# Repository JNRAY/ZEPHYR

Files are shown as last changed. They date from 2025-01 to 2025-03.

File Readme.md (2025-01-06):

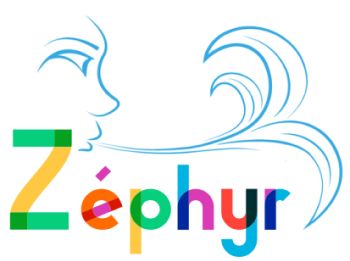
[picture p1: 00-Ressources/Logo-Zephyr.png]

## Network of sensors monitoring air quality parameters.  
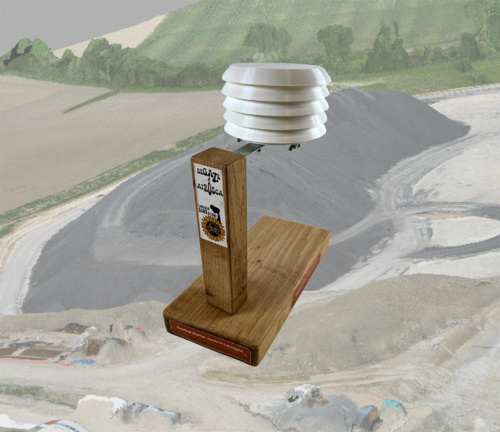
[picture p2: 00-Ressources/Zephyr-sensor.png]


*The Zéphyr sensor on its demonstration support and in the background of the image the pile of gravel from the Puylaurens power plant.*

The Zéphyr sensor is an instrument that measures up to 9 physical air quality parameters:

* Particles from 1 to 10µm: PM1, PM2.5, PM4 and PM10 
* Volatile Organic Compounds VOCs
* Nitrogen Oxides Nox
* Air humidity
* Ambient temperature
* CO2 content (optional)  

It was developed during the fight against the A69 motorway project (Tarn/Haute-Garonne, Occitanie region in France) to oppose the establishment of two bitumen asphalt mixing plants whose authorities government authorities did not fully appreciate public health and environmental issue**s.

The operation was carried out at the initiative of the Lauragais Sans Bitume [LSB](https://www.lauragais-sansbitume.fr/) collective, supported by 11 other local bitumen-free collectives.

The sensors and the computer architecture to manage the data were designed by a group of enlightened amateurs from the territory impacted by the power plants, supported by the Granas de Carderas association which distributes the sensors from its [HelloAsso](https://www.helloasso.com/associations/granas-de-carderas) sales website.

The sensors deployed (more than 60 to date) send their data every 5 minutes to a server which allows the owners of the sensors to access a dashboard and everyone to view the mapping of the quality of air in real time.

[For more information see our GitBook site:](https://rhizobiome.gitbook.io/atrosca-degaze)

## *Credits*

We would like to thank the people who participated, on a voluntary basis, in this initiative.
The people involved were able to provide their skills in various areas to make this project a reality:

* Design & technical design of circuits to operate sensors
* 3D printing and assembly of the boxes in which the sensors are embedded
* Provision of a server and hosting
* Integration of applications (open source) used to collect data
* Development of the dasboards presented here
* Coordination of the project and all the skills necessary to achieve this result

All this without forgetting the contributors who took the step of acquiring a Zéphyr sensor and making the measurements taken by them available.
THANKS !!

[Zéphyr](https://rhizobiome.gitbook.io/atrosca-degaze) © 2024 [LSB](https://www.lauragais-sansbitume.fr/) under the [CC BY-NC-SA 4.0](https://creativecommons.org/licenses/by-nc-sa/4.0/?ref=chooser-v1) Licence

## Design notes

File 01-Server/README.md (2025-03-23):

# LSB Server

_Page describing integration of so-called "LSB server", a solution designed to collect data from air quality sensors based on Sensirion SEN55 and SCD30 sensors driven by an ESP32 SOC_

# Foreword

## Open-source Software

In order to properly collect and expose data in the contxt for which this project has been set up, we intend to use only open-source and free-to-use software in order to keep costs low and show transparency to those that will provide and use the data we'll be providing.

Additionally, we don't intend to infringe any copyright or proprietary usage limitation by editors of software we choosed to rely on. We think that we're respecting this moto, but as there are many software and licenses involved here: this a complex situation. If you notice any chance that we're not respecting any of those: please notify us so can investigate and remediate...

## Prerequisites

Below are the assumptions that are made in order to properly host the software that are used in this context.

- You dispose of a server with **docker** and **docker compose** plugin installed.
- You dispose of a way to expose the server on the internet: either a hosted service or a broadband.
- You have a domain, prerefarably with a wildcard DNS resolution for any subdomains, to properly host web interfaces that will be built & used.
- You have a letsencrypt account in order to create SSL/TLS certificates used by those interfaces

# Technical documentation

We tried to stay as "standard" as possible, using official releases/images whenever possible and avoided customizing too much the software we integrated so this can be repeated and adapted by other willing to build analog solutions. Don't hesitate to refer to each used software documentation to understand and/or customize configuration to fit your needs and situation.

In the files provided in this repository, mostly docker-compose.yml file, one should consider replacing keywords between `<` and `>` by assets suited to its specific situation or configuration: those can be domain names, IPs, passwords, ...  
=> As a consequence, you'll have to edit/review all files when cloning this repository: comments embedded in files will help filling those values and provide guidance.

We prefered usage of publicly available **docker** images in order to allow better reproductibility of what we've done, so anyone can benefit from the work and design proposed here.  
**Docker** usage also allow for ease of use, configuration and backup of the solution.

## Installation

Please read through the whole **installation** chapter before jumping to **usage** and/or ask questions: many integration details are documented here.

### Clone git repo

As **root** user, if not already done, create a **docker** user, preferably with gid/uid = 1000 and clone this repo as this user's home folder:
```
useradd -u 1000 -g 1000 -b /home/docker -M docker
cd /home
git clone <REPO_URL>
mv REPO_NAME/docker ./
chown -R 1000:1000 ./docker
chown -R 472 ./docker/grafana

```
Now, just go trough all files, looking for keywords as mentioned earlier in order to put your values in place of those so you'll have usable configurations.

=> Below, you'll find a list of all keywords that would need to be replaced once repo is cloned:

| Keyword | File | Usage |  
|---|---|---|
| YOUR_DOMAIN | docker/traefik/docker-compose.yml | The domain name that will be used to host solution |
| YOUR_LETSENCRYPT_USER_EMAIL | docker/traefik/config/traefik.yml | Email of owner that is used for Letsencrypt SSL certificate |
| TRAEFIK_USER | docker/traefik/config/dynamic/middlewares.yaml | User to connect to Traefik web ui |
| TRAEFIK_PASSWORD | docker/traefik/config/dynamic/middlewares.yaml | Password for above user |
| TRAEFIK_PASSWORD | docker/traefik/config/dynamic/middlewares.yaml | Password hash of above password |
| YOUR_TRUSTED_IP | docker/traefik/config/dynamic/middlewares.yaml | Public IP that you trust (ex: admins of the solution, so they can connect though Traefik filtering |
| YOUR_DOMAIN | docker/wireguard/docker-compose.yml | The domain name that will be used to host solution |
| YOUR_PUBLIC_FQDN | docker/wireguard/docker-compose.yml | FQDN that will be used for VPN clients, likely `vpn.<YOUR_DOMAIN>` |
| WIREGUARD_BCRYPT_PASSWORD_HASH | docker/wireguard/docker-compose.yml | Hash of the password used to acces Wireguard admin web UI. Beware of carefully reading editor documentation that comment in the file points you to for hash generation...|
| PRIVATE_IP_OF_SERVER | docker/wireguard/docker-compose.yml | Private IP of system that will be used to host solution |
| MQTT_USER | docker/mqtt/mosquitto/config/mosquitto.conf | Connection user for MQTT clients |
| YOUR_DOMAIN | docker/mqtt/telegraf-sensor/conf/telegraf.conf | The domain name that will be used to host solution |
| INFLUXDB_ORGANIZATION_NAME | docker/mqtt/telegraf-sensor/conf/telegraf.conf | Organization that you created on InfluxDB admin web UI |
| INFLUXDB_BUCKET_NAME | docker/mqtt/telegraf-sensor/conf/telegraf.conf | Name of bucket that you created on InfluxDB admin web UI |
| INFLUXDB_TOKEN_VALUE | docker/mqtt/telegraf-sensor/conf/telegraf.conf | Value of token for above bucket that you created on InfluxDB admin web UI |
| SENSORS_MQTT_TOPIC | docker/mqtt/telegraf-sensor/conf/telegraf.conf | Value of topic you choosed for sensors to send their metrics |
| MQTT_USER | docker/mqtt/telegraf-sensor/conf/telegraf.conf | User that Telegraf will use to get values from MQTT, that you created earlier in the installation process |
| MQTT_PASSWORD | docker/mqtt/telegraf-sensor/conf/telegraf.conf | Password corresponding to aboce user |
| YOUR_DOMAIN | docker/influxdb/docker-compose.yml | The domain name that will be used to host solution |
| YOUR_DOMAIN | docker/grafana/docker-compose.yml | The domain name that will be used to host solution |
| SMTP_SERVER_IP | docker/grafana/docker-compose.yml | IP of SMTP server to allow Grafana to send emails (optional) |
| SMTP_SERVER_PORT | docker/grafana/docker-compose.yml | Port of SMTP server to allow Grafana to send emails (optional) |
| SMTP_SENDER_EMAIL | docker/grafana/docker-compose.yml | Sender adress used by Grafana to send emails (optional) |
| GRAFANA_ORGANIZATION_NAME | docker/grafana/docker-compose.yml | Organization (you created in Grafana web UI) to allow to publicly expose dashboards without users authentication (optional) |
| PUT_DASHBOARD_DESCRIPTION_HERE | docker/grafana/sen55-graphs.json | Description of the dashboard for users to understand what's in the dashboard |
| SENSOR_DATASOURCE_ID | docker/grafana/sen55-graphs.json | ID of datasource you creaated in Grafana web UI, pointing to InfluxDB bucket for sensors collected data |
| SENSOR_MQTT_TOPIC | docker/grafana/sen55-graphs.json | MQTT topic used by sensors to send data to MQTT |
| PUT_DASHBOARD_DESCRIPTION_HERE | docker/grafana/scd30-graphs.json | Description of the dashboard for users to understand what's in the dashboard |
| SENSOR_DATASOURCE_ID | docker/grafana/scd30-graphs.json | ID of datasource you creaated in Grafana web UI, pointing to InfluxDB bucket for sensors collected data |
| SENSOR_MQTT_TOPIC | docker/grafana/scd30-graphs.json | MQTT topic used by sensors to send data to MQTT |

### Docker configuration

To avoid IP conflict with local network and fix some enrtypoints, we fixed the IP used bu docker, especially the **docker0** bridge interface.  
=> This is done by configuring it in `/etc/docker/daemon.json` fille: refer to the `daemon.json` file in the root of this repository.

### Folder structure

For hosting containers, we choosed to add a **docker** user to the system (user without any admin privileges with uid/gid=1000), but any user will do.  
=> As a consequence, the `docker` folder in this repo is actually the `/home/docker` folder on the server: you may need to adapt volumes path in the compose files to your situation. But, the easier would be to stick to this structure, so you'll have minimal changes to carry out in compose files.

### Traefik

To allow quick and easy configuration and hosting of web interfaces, we rely on the **traefik** container which is a reverse proxy able to generate SSL certificates from **Letencrypt** for each subdomain that will be used in other containers.  

Port 80, should be exposed to the internet so **traefik** can automatically generate SSL certificates through **Letencrypt** certificate athority.  
Port 443 is only needed if you're willing to expose the WebUIs to the internet: but beware of using proper filtering and secure passwords on your interfaces if you're hoing that way !

### Wireguard

A Wireguard VPN will be used so sensors can connect to server to push air-quality measures to server: we choose to use the **wgeasy** container to allow easy wireguard integration/configuration.  

Although it is a docker container, and on CentOS at least, this needs a bit of system tuning on server by adding the `ip_tables` module to kernel at boot time: you should add commands to your `/etc/rc.local` file: see the `rc.local` file in the `docker/wireguard` folder of this repo (or possibly create a file in the `/etc/modprobe.d/` to have this module probed at start-up).  
We prefered the `rc.local` solution as we've added a restart for **mosquitto** container as it does not properly starts on every reboot the server may experience.

### InfluxDB

In order to store measures sent by sensors, we need a DB able to handle so called "time-series": we choosed **InfluxDB**.  
When running container for first time, you'll have to create via web UI:

* an organization
* a bucket (= a DB) for sensor data
* optional: a bucket for weather data, if you choose to collect weather from external sources
* a token with write permission to each bucket for Telegraf (to be used in **mqtt** docker stack)
* a token with read permission to each bucket for Grafana (to be used in **grafana** docker stack)

### MQTT

Sensors send data using MQTT protocol to the server. For the MQTT stack, we choose to use **mosquitto** container as a MQTT broker and **telegraf** as client to get MQTT messages.

A single docker compose file for both container is in the `docker/mqtt` folder of this repo.  
It also contains additional telegraf container for collecting weather data from a public station so we can display wind direction and speed on a map with sensors (see the **grafana** stack).

### Grafana

To display sensors data in bashboards, **Grafana** is a perfect tool.  
Container use a specific uid (472) when running, so don't omit to `chown -R 472 /home/docker/grafana` after cloning this repo.

We have set up dashboards showing graphs and maps with sensors:

* create datasources in Grafana web UI corresponding to each InfluxDB bucket and note their ID aside. When adding datasources, you'll need to use bucket tokens created earlier and user HTTP header authentication. Refer to [Grafana documentation about InfluxDB datasource](https://grafana.com/docs/grafana/latest/datasources/influxdb/configure-influxdb-data-source/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)
* refer to JSON files in `docker/rafana` folder of this repo: those have to be imported in the web UI, then adapted to you situation (datasource ID, locations, sensor names, ...).

## Usage

### Accesses
Once installation is properly done, you should consider below recapitulative information to properly  use the solution:

<u>Ports to be publicly exposed:</u>

| Port | Protocol | Usage |
|---|---|---|
| 80 | TCP | For Traefik to be able to generate SSL certificates |
| 443 | TCP | Optional: to publicly expose web UI, if needed |
| 51820 | UDP | For sensors to extablish Wireguard VPN connection |

<u>Available web UI URLs:</u>

| URL | Usage |
|-----|---|
| `https://air-quality.<YOUR_DOMAIN>` | Grafana web UI, used for administration and exposing dashboards |
| `https://influxdb.<YOUR_DOMAIN>` | InfluxDB admin web UI and API used as Grafana datasource |
| `https://traefik.<YOUR_DOMAIN>` | Traefik dashboard, to view & check reverse proxy configuration |
| `https://vpn.<YOUR_DOMAIN>` | Wireguard admin web UI used to create & view VPN accounts for sensors. It is also the VPN server address to be used in the ESP32 code |

### VPN keys

First thing is to create a VPN account for a sensor (one account for each sensor) on the Wireguard web UI.  
As ESP32 library in the code from [ESP32 code repo](https://repo.url) does not take into account pre-shared key, they'll have to be removed from configuration that the webmin created.
To achieve this, stop the wireguard container and edit the `docker/wireguard/data/wg0.json` file and remove the value for `preSharedKey` for each account you created but keep the key in the file or another one will be created, as shown in below snippet example:

```json
(...)
"preSharedKey": "",
(...)
```

### Configure sensor

Refer to [ESP32 code repo](https://github.com/JNRAY/ZEPHYR/tree/main/02-Sensor/03-XIAO-C3-code#:~:text=03%2DXIAO%2DC3%2D-,code) and include VPN keys in header file before compilation and upload firware to ESP32.  
When sensor is restarted and configured to connect to a Wifi network, you should be able to see it connecting at MQTT level by looking to **mosquitto** container logs.

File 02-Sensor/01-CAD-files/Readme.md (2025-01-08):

### Cad Files

Cad files in Fusion 360 and STEP format

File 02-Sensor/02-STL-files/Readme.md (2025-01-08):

### Print settings
Filament material: PLA

* Color: white.
* Infill: 20%.
* Resolution: 0.2.
* For intermediate level, Top cover  and Sensor support, Supports: Yes.
* For Bottom, Support: No.

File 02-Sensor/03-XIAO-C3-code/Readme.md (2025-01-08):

# Zéphyr XIAO-C3 code installation and Download

## Basic software installation

### Install Vscode

Go to [https://code.visualstudio.com/]() and download the stable build for your operating system.

Launch Vscode.

### Instam PlatforIO extension on Vscode

In Vscode Extension seache and load PlartforIO IDE

Download XIAO-ESP32-C3 source code folder and copy in your conputer, open it from PIO Home/Open Project Quick Acess Menu.

## Zéphyr code configuration

You need to replace the values betxeen < > for:

### Server Configuration

From line 64 to 96 you need to update the folloving variables depending on your server configuration.

Name of the .h include file:

`<SEN55_SENSOR_ID>` (e.g. SEN55-001 or SCD30-001 if CO2 captor is installed)

Wireguard Configuration:

`public_key`&nbsp;&nbsp;&nbsp;&nbsp;&nbsp;&nbsp;&nbsp;&nbsp;&nbsp;&nbsp;&nbsp;&nbsp;&nbsp;&nbsp;`<WIREGUARD_PUBLIC_KEY>`  
`endpoint_address` `<YOUR_DOMAIN>`  
`endpoint_port` &nbsp;&nbsp;&nbsp;&nbsp;&nbsp;&nbsp;`<WIREGUARD_PORT>`

MQTT configuration:

`mqtt-Server` &nbsp;&nbsp;&nbsp;`<MQTT_SERVEUR_IP>`  
`mqttPort `&nbsp;&nbsp;&nbsp;&nbsp;&nbsp;&nbsp;&nbsp;&nbsp;&nbsp;&nbsp;`<MQTT_SERVEUR_PORT>`  
`mqttUser` &nbsp;&nbsp;&nbsp;&nbsp;&nbsp;&nbsp;&nbsp;&nbsp;&nbsp;`<MQTT_USER>`  
`mqttPassword` &nbsp;`<MQTT_PASSWORD>`

### Include .h file configuration for each captor

There is one .h include file for each sensor:

Sensor name and plant location:

`sensor` `SEN55-<SENSOR_ID>` (e.g. SEN55-001 or SCD30-001 if CO2 captor is installed)  
`zone` &nbsp;&nbsp;&nbsp;&nbsp;`<PLANT_LOCATION>` (Several plant location could be used if needed)

Sensor position (Used for the cartography in Grafana):

`longi` `<LONGITUDE>` of the Sensor  
`lat` &nbsp;&nbsp;&nbsp;&nbsp;`<LATITUDE>` of the Sensor

Mqtt Topic:

`topic` `<SENSOR_MQTT_TOPIC/SEN55-SENSOR_ID>`D (e.g. Environement/SEN55-001)

Wireguard configuration:

`privatr_key` `<WIREGUARD_PRIVATE_KEY>`  
`local_ip` &nbsp;&nbsp;&nbsp;&nbsp;&nbsp;&nbsp;`<WIREGUARD_SENSOR_IP>`

### Other configurations

From line 30 to 63 there is 4 viriables (See comment for definition):

`DEBUG`	&nbsp;&nbsp;&nbsp;&nbsp;&nbsp;&nbsp;&nbsp;&nbsp;&nbsp;&nbsp;&nbsp;0 or 1  
`SEND_DATA` &nbsp;&nbsp;0 or 1  
`WIFI_RESET` 0 or 1  
`SDC30` &nbsp;&nbsp;&nbsp;&nbsp;&nbsp;&nbsp;&nbsp;&nbsp;&nbsp;&nbsp;&nbsp;0 or 1

### Upload Code

[See GitBook site:](https://rhizobiome.gitbook.io/atrosca-degaze/le-capteur-zephyr/montage)

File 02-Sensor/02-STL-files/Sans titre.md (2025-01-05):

### Print settings
Filament material: PLA

* Color: white.
* Infill: 20%.
* Resolution: 0.2.
* For intermediate level, Bottom and Sensor support, Supports: Yes.
* For Top cover, Support: No.

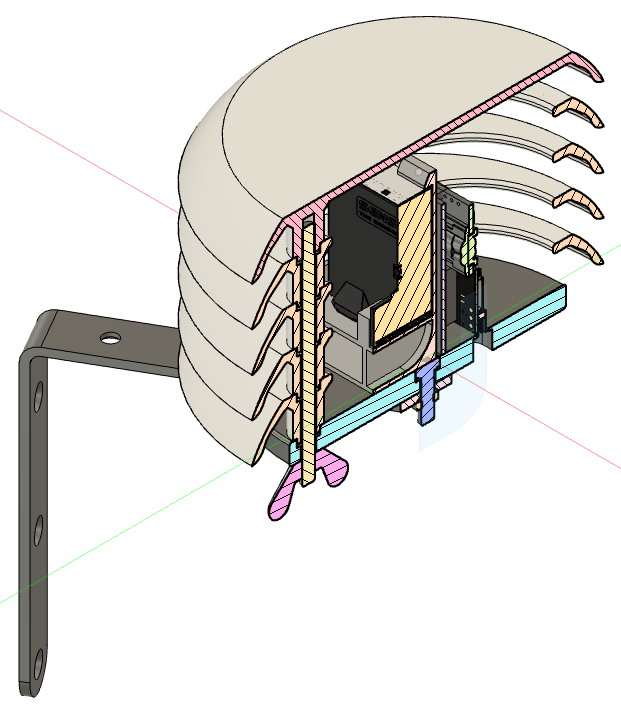
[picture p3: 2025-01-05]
00-Ressources/Cross-section.png

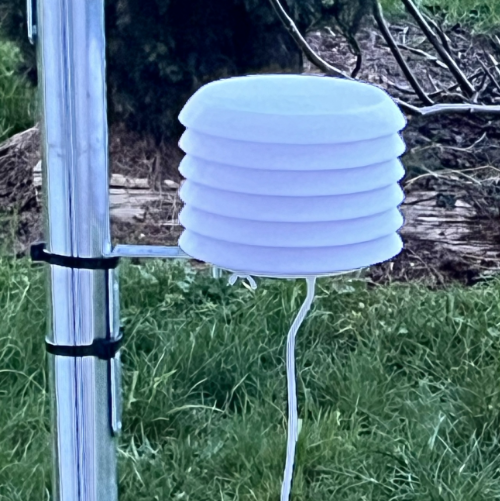
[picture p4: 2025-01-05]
00-Ressources/Photo.png

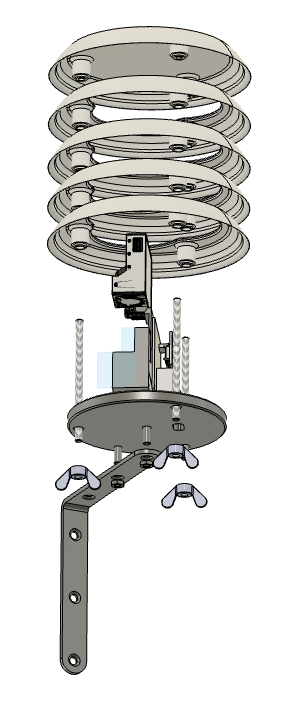
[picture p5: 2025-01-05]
00-Ressources/Exploded-view.png

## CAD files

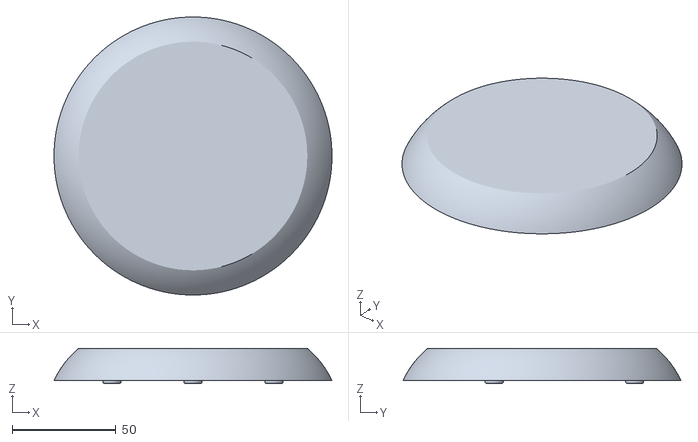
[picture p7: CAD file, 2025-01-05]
02-Sensor/02-STL-files/Top-cover.stl
133.8 x 133.8 x 17.0

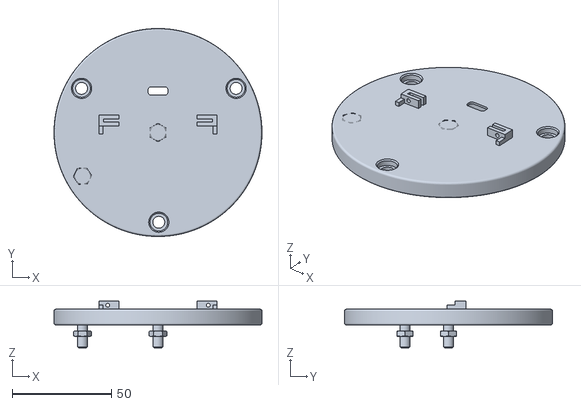
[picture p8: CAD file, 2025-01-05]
02-Sensor/02-STL-files/Bottom.stl
105.0 x 105.0 x 23.5

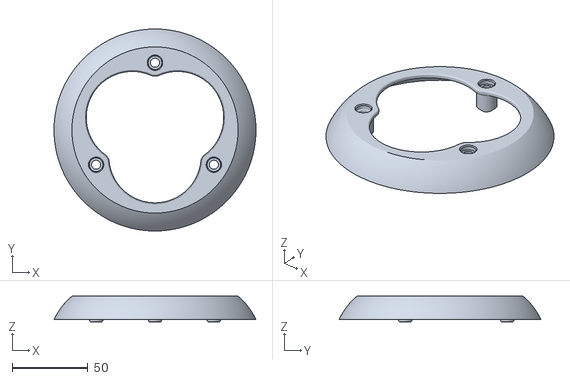
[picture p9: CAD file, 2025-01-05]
02-Sensor/02-STL-files/Intermediate-level.stl
133.8 x 133.8 x 17.0

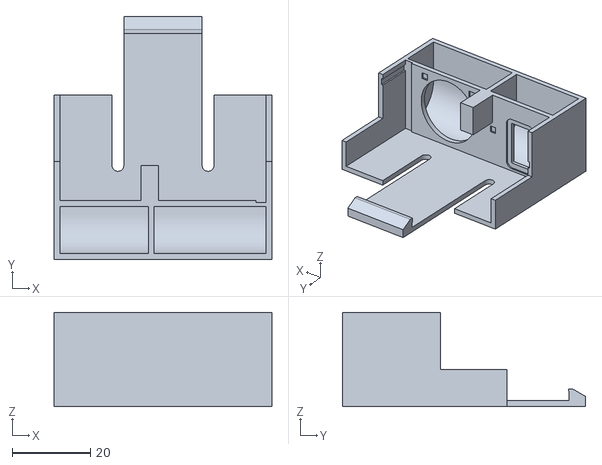
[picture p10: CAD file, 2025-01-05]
02-Sensor/02-STL-files/SEN55-support.stl
55.5 x 62.0 x 24.0

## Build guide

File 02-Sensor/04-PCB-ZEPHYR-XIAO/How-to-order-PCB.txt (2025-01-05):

How to Order PCB

Please refer to:
https://docs.easyeda.com/en/PCB/Order-PCB

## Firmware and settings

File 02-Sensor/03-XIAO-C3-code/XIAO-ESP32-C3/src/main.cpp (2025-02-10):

/*
  Programme Envirennement - SEN55-XXX
  Author: Jean Noël Raynaud
  Version     Date        Modification

  V1        30/03/2024    Création of final version
  V2        21/05/2024    Minor update for DEBUG
  V3        16/06/2024    Integration WiFiManagement librry
  V4        26/06/2024    Integration include file for vaiables
  V5        25/07/2024    Modification IP adress of MQTT Server 
  V6        28/07/2024    Integration of SCD30 C02 captor
  V7        28/01/2025    Adaptation for WiFi connection router with only WPA(TKIP/AES) protocol and addition
                          of timeout for WifiManager AutoConnectAP

  Copywrigt: 
    For SEN55 code part: Copyright (c) 2021, Sensirion AG under the BSD 3-Clause License
    For the other part: Copyright (c) 2024, Zéphir - LSB under the CC BY-NC-SA 4.0 License
*/

// Librairies

#include <Arduino.h>
#include <ArduinoJson.h>
#include <SensirionI2CSen5x.h>
#include <SensirionCore.h>
#include <WiFiManager.h>
#include <PubSubClient.h>
#include <SensirionI2cScd30.h>
#include <WireGuard-ESP32.h>
#include "time.h"
#include "math.h"


// ******************************************************************************
// Variable DEBUG put:
//    0 if production
//    1 if test or coding mode to see the Serial.print information in the monitor
// ******************************************************************************

#define DEBUG 0

// *********************************************************************************
// Variable SEND_DATA put:
//    0 Data set sent every hour and 1/2 hour. Synchronised whit ntp server
//    1 Data set sent every 5 mins 300000 Milliseconds and we remove 6.25 secondes
//      to integrate calculation time
// *********************************************************************************

#define SEND_DATA 1
const int send_data = 300000-6250;

// *********************************************************************************
// Variable WIFI_RESET put:
//    0 To keep current stored WIFI SSID and PASSWORD
//    1 To reset current stored WIFI SSID and PASSWORD You will need to upload the
//    code again with 0 to keep your stored WIFI SSID and PASSWORD
// *********************************************************************************

#define WIFI_RESET 0

// *********************************************************************************
// Variable SCD30 C02 Captor put:
//    0 If SCD30 Captor is not installed
//    1 If SCD30 Captor is installed
// *********************************************************************************

#define SCD30 0

// *********************************************************************************
// All paremeters between < > bellow must be replaced by your own serveur parameters
// *********************************************************************************

    // **********************************************************************
    // Variables to be updated for each sensor inside the SEN55-<SENSOR_ID>.h
    // files located in the include directory
    // **********************************************************************

    #include <SEN55-<SENSOR_ID>.h>

    // *****************************************************************
    // Variables to be updated depending of your server environnment
    // *****************************************************************
      
    // WireGuard configuration

      char public_key[] = "<WIREGUARD_PUBLIC_KEY>";
      char endpoint_address[] = "vpn.<YOUR_DOMAIN>";  // IP of Wireguard endpoint to connect to.
      int endpoint_port = <WIREGUARD_PORT>;

      static WireGuard wg;

    // MQTT server connection variables

      const char* mqttServer = "<MQTT_SERVEUR_IP>";
      const int mqttPort = <MQTT_SERVEUR_PORT>;
      const char* mqttUser = "<MQTT_USER>";
      const char* mqttPassword ="<MQTT_PASSWORD>";

// ********************************************************************************
// End of parameters to be updated depending of your serveor parameters
// ********************************************************************************

// Retention of messages true or false - if false no message sent
  
  boolean retained;

// WiFi and MQTT client configuration

  WiFiClient espClient;
  PubSubClient client(espClient);

// NTP server variable for Local Time to be updated depending of your location

  const char* ntpServer = "fr.pool.ntp.org";
  const char* localTimeZone = "CET-1CEST,M3.5.0,M10.5.0/3";

// *********************************************************************
// End Variables to be updated depending of your server environnment
// Do not modify the code below
// *********************************************************************

// Sensirrion SEN55

// The commands used use up to 48 bytes. On some Arduinos,
// the default buffer space is not large enough

#define MAXBUF_REQUIREMENT 48

#if (defined(I2C_BUFFER_LENGTH) &&                 \
     (I2C_BUFFER_LENGTH >= MAXBUF_REQUIREMENT)) || \
     (defined(BUFFER_LENGTH) && BUFFER_LENGTH >= MAXBUF_REQUIREMENT)
#define USE_PRODUCT_INFO
#endif

SensirionI2CSen5x sen5x;

// SCD30

SensirionI2cScd30 sensor2;

static char errorMessage[128];
static int16_t error;

// FUnction print Local Time

void printLocalTime(){
  struct tm timeinfo;
  if(!getLocalTime(&timeinfo)){
    Serial.println("Fonstion printLocalTime: Impossible d'obtenir l'heure");
    return;
  }
  Serial.print("Date et heure: ");
  Serial.println(&timeinfo, "%d/%m/%Y %H:%M:%S");
}

// FUnction reboot

void restartEps32(String error_message){
  if (DEBUG) {
    Serial.println();
    Serial.println("Restart ESP32");
    Serial.println(error_message);
    Serial.println();
  }
  ESP.restart();
}

// Function printModuleVersions

void printModuleVersions() {
  uint16_t error;
  char errorMessage[256];

  unsigned char productName[32];
    uint8_t productNameSize = 32;

    error = sen5x.getProductName(productName, productNameSize);

  if (error) {
    Serial.print("SEN-55 Erreur getProductName(): ");
    errorToString(error, errorMessage, 256);
    Serial.println(errorMessage);
  } else {
    Serial.print("SEN-55 ProductName:");
    Serial.println((char*)productName);
  }

  uint8_t firmwareMajor;
  uint8_t firmwareMinor;
  bool firmwaredebug;
  uint8_t hardwareMajor;
  uint8_t hardwareMinor;
  uint8_t protocolMajor;
  uint8_t protocolMinor;

  error = sen5x.getVersion(firmwareMajor, firmwareMinor, firmwaredebug,
                            hardwareMajor, hardwareMinor, protocolMajor,
                            protocolMinor);
  if (error) {
    Serial.print("SEN-55 Erreur getVersion(): ");
    errorToString(error, errorMessage, 256);
    Serial.println(errorMessage);
  } else {
    Serial.print("SEN-55 Firmware: ");
    Serial.print(firmwareMajor);
    Serial.print(".");
    Serial.print(firmwareMinor);
    Serial.print(", ");
    Serial.print("Hardware: ");
    Serial.print(hardwareMajor);
    Serial.print(".");
    Serial.println(hardwareMinor);
  }
}

// Function printSerialNumber

void printSerialNumber() {
  uint16_t error;
  char errorMessage[256];
  unsigned char serialNumber[32];
  uint8_t serialNumberSize = 32;

  error = sen5x.getSerialNumber(serialNumber, serialNumberSize);
  if (error) {
    Serial.print("SEN-55 Erreur getSerialNumber(): ");
    errorToString(error, errorMessage, 256);
    Serial.println(errorMessage);
  } else {
    Serial.print("SEN-55 SerialNumber:");
     Serial.println((char*)serialNumber);
  }
}

// *****
// Setup
// *****

void setup() {

  Serial.begin(115200);

  // while (!Serial){} // Do not use for XIAO cart

  delay(1000);

  if (DEBUG) {
    Serial.println();
    Serial.println("-------------------------");
    Serial.println("Début setup");
    Serial.println("-------------------------");
  }

  // SEN55

  Wire.begin();

  sen5x.begin(Wire);

    uint16_t error;
    char errorMessage[256];
    error = sen5x.deviceReset();

  if (DEBUG) {

    if (error) {("SEN-55 Erreur deviceReset(): ");
      errorToString(error, errorMessage, 256);
      Serial.println(errorMessage);
    }

    printSerialNumber();
    printModuleVersions();

  }

  // Set a temperature offset in degrees Celsius
  // Note: supported by SEN54 and SEN55 sensors
  // By default, the sensor temperature and humidity outputs
  // are compensated for the self-heating of the modules. If the module is
  // contained in a box, temperature compensation may require
  // to be adapted to integrate the change in thermal coupling and
  // self-heating of other components of the device.
  //
  // A guide to achieving peak performance, including benchmarks
  // Examples of mechanical design can be found in the application note
  // “SEN5x – Temperature compensation instruction” on www.sensirion.com.
  // Please refer to these application notes for more information
  // on the advanced compensation parameters used
  // in `setTemperatureOffsetParameters`, `setWarmStartParameter` and
  // `setRhtAccelerationMode`.
  //
  // Adjust tempOffset to account for additional temperature offsets
  // self-heating of the SEN module exceeded.

  float tempOffset = 0.0;
  error = sen5x.setTemperatureOffsetSimple(tempOffset);
  if (DEBUG) {
    if (error) {
      Serial.print("SEN-55 Erreur setTemperatureOffsetSimple(): ");
      errorToString(error, errorMessage, 256);
      Serial.println(errorMessage);
    } else {
      Serial.print("SEN-55 Temperature Offset set to ");
      Serial.print(tempOffset);
      Serial.println(" deg. Celsius (SEN54/SEN55 only");
    }
  }

  // Start Measurement

  error = sen5x.startMeasurement();

  if (DEBUG) {
    if (error) {
      Serial.print("SEN-55 Erreur startMeasurement(): ");
      errorToString(error, errorMessage, 256);
      Serial.println(errorMessage);
    }
    Serial.println("Start SEN55 Measurement");
    Serial.println();
  }

  // SCD30

  if (SCD30) {
    Serial.setDebugOutput(true);
    Wire.begin();
    sensor2.begin(Wire, SCD30_I2C_ADDR_61);

    if (DEBUG) {
      Serial.print("SCD30 I2C Adress: ");
      Serial.println(SCD30_I2C_ADDR_61);
    }

    sensor2.stopPeriodicMeasurement();
    sensor2.softReset();
    delay(2000);
    uint8_t major = 0;
    uint8_t minor = 0;
    error = sensor2.readFirmwareVersion(major, minor);
    if (DEBUG) {
      if (error != NO_ERROR) {
          Serial.print("SDC 30 Error trying to execute readFirmwareVersion(): ");
          errorToString(error, errorMessage, sizeof errorMessage);
          Serial.println(errorMessage);
          return;
      }
      Serial.print("SCD30 firmware version major: ");
      Serial.print(major);
      Serial.print("\t");
      Serial.print("minor: ");
      Serial.print(minor);
      Serial.println();
      error = sensor2.startPeriodicMeasurement(0);
      if (error != NO_ERROR) {
          Serial.print("SCD30 Error trying to execute startPeriodicMeasurement(): ");
          errorToString(error, errorMessage, sizeof errorMessage);
          Serial.println(errorMessage);
          return;
      }
    }
  }

  // Wifi connexion

  WiFi.mode(WIFI_STA); // explicitly set mode, esp defaults to STA+AP

  if (DEBUG) {
    Serial.println();
    Serial.println("Debut setup WiFi");
    Serial.println();
  }
    
  // WiFiManager, Local intialization. Once its business is done, there is no need to keep it around
  
  WiFiManager wm;

  // For WiFi router with only WPA(TKIP/AES) protocol

  WiFi.setMinSecurity(WIFI_AUTH_WPA_PSK);

  // Set time out fot WiFiManager AutoConnectAP portal 60 second

  wm.setConfigPortalTimeout(60);
 
  // Reset settings - wipe stored credentials for testing
  // these are stored by the esp library
  
  if (WIFI_RESET) {
    if (DEBUG) {
      Serial.println("Reset WiFi SSID and Password");
      Serial.println();
    }
    wm.resetSettings();
  }

  // Automatically connect using saved credentials,
  // if connection fails, it starts an access point with the specified name ( "AutoConnectAP"),
  // if empty will auto generate SSID, if password is blank it will be anonymous AP (wm.autoConnect())
  // then goes into a blocking loop awaiting configuration and will return success result
 
  bool res;

  // res = wm.autoConnect(); // auto generated AP name from chipid
  // res = wm.autoConnect("AutoConnectAP"); // anonymous ap
  // res = wm.autoConnect("AutoConnectAP","password"); // password protected ap

  res = wm.autoConnect("AutoConnectAP");
  
  if(!res) {
    if (DEBUG) {
      Serial.println();
      Serial.println("Failed to connect to WiFI");
      Serial.println("EPS Restart");
      Serial.print("res = ");
      Serial.println(res);
      Serial.println();
    }
    ESP.restart();
  } 
  else {
    //if you get here you are connected to the WiFi
    if (DEBUG) {
      Serial.println();   
      Serial.print("Connected to WiFi network: ");
      Serial.print("Local ESP32 IP: ");
      Serial.println(WiFi.localIP());
      Serial.print("res = ");
      Serial.println(res);
      Serial.println();
    }
  }

  // WireGuard connection

  if (DEBUG) {
    Serial.println();
    Serial.println("Start WireGuard Connexion");
    Serial.println("Adjusting system time...");
  }
  
  configTzTime(localTimeZone, ntpServer);
  struct tm timeinfo;

  if (!getLocalTime(&timeinfo)) {
    if (DEBUG) {
      Serial.println("impossible to get the time");
    }
  }

  if (DEBUG) {
    Serial.print("Date et heure: ");
    Serial.println(&timeinfo, "%d/%m/%Y %H:%M:%S");
    Serial.println();
    Serial.println("Connected. Initializing WireGuard...");
    Serial.print("Local_ip: ");
    Serial.println(local_ip);
    Serial.print("Private_key: ");
    Serial.println(private_key);
    Serial.print("Endpoint_address: ");
    Serial.println(endpoint_address);
    Serial.print("Public_key: ");
    Serial.println(public_key);
    Serial.print("Endpoint_port: ");
    Serial.println(endpoint_port);
  }

  if (wg.begin(local_ip,private_key,endpoint_address,public_key,endpoint_port)) {
    if (DEBUG) {
      Serial.println("WireGuard Connection OK");
    }
  } else {
    if (DEBUG) {
      Serial.println("WireGuard Connection FAIL");
    }
  }

  if (DEBUG) {
    Serial.println();
    Serial.println("-------------------------");
    Serial.println("End setup");
    Serial.println("-------------------------");
    Serial.println();
  }
}

// ****
// Loop
// ****

void loop() {

  if (DEBUG) {
    Serial.println("-------------------------");
    Serial.println("Start loop");
    Serial.println("-------------------------");
  }

  String error_message;

  // We configure the ntp server and retrieve the time

  configTzTime(localTimeZone, ntpServer);
  struct tm timeinfo;

  if (!getLocalTime(&timeinfo)) {
    if (DEBUG) {
      Serial.println("impossible to get the time");
    }
  }
  
  if (DEBUG) {
    printLocalTime();
    Serial.println();
  }
  
  if(SEND_DATA) {
    // 1 data set sent every 5 minutes = 300000 Milliseconds
    if (DEBUG) {
        Serial.println ("SEND_DATA = 1");
        Serial.println ();
      }
  } else {
    // 1 data set sent every hour and 1/2 hour

    int minutes = timeinfo.tm_min;
    int secondes = timeinfo.tm_sec;

    if (DEBUG) {
      Serial.println ("SEND_DATA = 0");
      Serial.println ();
      Serial.println ("minutes = " + String(minutes) + " seconds = " + String(secondes));
    }

    if (minutes == 0) {
      if (DEBUG) {
        Serial.println ("minutes = 0 minutes");
      }
    } else if (minutes < 30) {
      minutes = (30 - minutes);
        if (DEBUG) {
          Serial.println ("minutes < ou = 30 minutes = " + String(minutes));
        }
    } else if (minutes == 30) {
      minutes = 0;
      if (DEBUG) {
        Serial.println ("minutes = 0 minutes");
      }
    } else if (minutes > 30) {
      minutes = (60 - minutes);
      if (DEBUG) {
        Serial.println ("minutes > 30 minutes = " + String(minutes));
      }
    } 

    if (minutes > 0) {
      if (DEBUG) {
        Serial.println("We wait = " + String(minutes) + " minutes - " + String(secondes) + " secondes and delay = " + String((minutes * 60000) - ((secondes * 1000) + 2000)) + " millisecondes");
        printLocalTime();
        Serial.println();
      }
      // We add 2 secondes = 2000 millisceondes to integrate calculation time
      delay((minutes * 60000) - ((secondes * 1000) + 2000));
    } else {
      if (DEBUG) {
        Serial.println("Minutes = 0, we continue the program");
        printLocalTime();
        Serial.println();
      }
    }
  }

  // SEN55

  uint16_t error;
  char errorMessage[256];

  delay(1000);

  // Read Measurement

  float massConcentrationPm1p0;
  float massConcentrationPm2p5;
  float massConcentrationPm4p0;
  float massConcentrationPm10p0;
  float ambientHumidity;
  float ambientTemperature;
  float vocIndex;
  float noxIndex;

  error = sen5x.readMeasuredValues(
  massConcentrationPm1p0, massConcentrationPm2p5, massConcentrationPm4p0,
  massConcentrationPm10p0, ambientHumidity, ambientTemperature, vocIndex,
  noxIndex);

  if (error) {
    if (DEBUG) {
      Serial.print("Erreur readMeasuredValues(): ");
      errorToString(error, errorMessage, 256);
      Serial.println(errorMessage);
    }
    delay(2000);
    String error_message = "";
    restartEps32(error_message);
  } else {
    if (DEBUG) {
      Serial.println("Données Capteur SEN55: ");
      printLocalTime();
      Serial.print("MassConcentrationPm1p0:");
      Serial.print(massConcentrationPm1p0);
      Serial.println();
      Serial.print("MassConcentrationPm2p5:");
      Serial.print(massConcentrationPm2p5);
      Serial.println();
      Serial.print("MassConcentrationPm4p0:");
      Serial.print(massConcentrationPm4p0);
      Serial.println();
      Serial.print("MassConcentrationPm10p0:");
      Serial.print(massConcentrationPm10p0);
      Serial.println();
      Serial.print("AmbientHumidity:");
      if (isnan(ambientHumidity)) {
        Serial.print("n/a");
      } else {
        Serial.print(ambientHumidity);
      }
      Serial.println();
      Serial.print("AmbientTemperature:");
      if (isnan(ambientTemperature)) {
        Serial.print("n/a");
      } else {
        Serial.print(ambientTemperature);
      }
      Serial.println();
      Serial.print("VocIndex:");
      if (isnan(vocIndex)) {
        Serial.print("n/a");
      } else {
        Serial.print(vocIndex);
      }
      Serial.println();
      Serial.print("NoxIndex:");
      if (isnan(noxIndex)) {
        Serial.println("n/a");
      } else {
        Serial.println(noxIndex);
      }
    }
  }

  // SCD30

  float co2Concentration = 0.0;
  float temperature = 0.0;
  float humidity = 0.0;

  if (SCD30) {
    delay(1500);
    error = sensor2.blockingReadMeasurementData(co2Concentration, temperature, humidity);
    if (error != NO_ERROR) {
      if (DEBUG) {
      Serial.print("SCD30 Error trying to execute blockingReadMeasurementData(): ");
      errorToString(error, errorMessage, sizeof errorMessage);
      Serial.println(errorMessage);
      return;
      }
      delay(2000);
      String error_message = "";
      restartEps32(error_message);
    } else {
      if (DEBUG) {
        Serial.println();
        Serial.println("Données Capteur SCD30:");
        Serial.print("co2Concentration: ");
        Serial.println(co2Concentration);
      }
    }
  }

  // JSON File

  if (DEBUG) {
    Serial.println();
    Serial.println("Start JSON");
  }

  StaticJsonDocument<700> doc;
  
  doc["Sensor"] = sensor;
  doc["Zone"] = zone;
  doc["Long"] = longi;
  doc["Lat"] = lat;
  doc["Pm1p0"] = massConcentrationPm1p0;
  doc["Pm2p5"] = massConcentrationPm2p5;
  doc["Pm4p0"] = massConcentrationPm4p0;
  doc["Pm10p0"] = massConcentrationPm10p0;
  doc["Humidity"] = ambientHumidity;
  doc["Temperature"] = ambientTemperature;
  doc["VOC"] = vocIndex;
  doc["NOx"] = noxIndex;
  if (SCD30) {
    doc["CO2"] = co2Concentration;
  }

  if (DEBUG) {
    Serial.println("End JSON");
    Serial.println();
  }

  // MQTT connexion

  client.setServer(mqttServer, mqttPort);

  while (!client.connected()) {
    if (DEBUG) {
      Serial.println("Connection to the MQTT server...");
    }
  
    if (client.connect(sensor , mqttUser, mqttPassword)) {
      if (DEBUG) {
        Serial.println("MQTT server connected");
      }
    } else {
      if (DEBUG) {
        Serial.print("MQTT connection failure with status: ");
        Serial.println(client.state());
        Serial.print("mqttserver: ");
        Serial.println(mqttServer);
        Serial.print("mqttPort: ");
        Serial.println(mqttPort);
        Serial.print("sensor: ");
        Serial.println(sensor);
        Serial.print("mqttUser: ");
        Serial.println(mqttUser);
        Serial.print("mqttPassword: ");
        Serial.println(mqttPassword);

      }
      delay(2000);
      String error_message = "";
      restartEps32(error_message);
    }
  }

  // Send MQTT message

  if (DEBUG) {
    Serial.print("Send message to MQTT topic server: ");
    Serial.println(topic);
  }

  client.beginPublish(topic, measureJson(doc), retained);
  if (DEBUG) {
    Serial.println("Start publication");
  }

  serializeJson(doc, client);

  if (DEBUG) {
    Serial.println("serializeJson");
   }

  boolean rc = client.endPublish();

  delay(5000);

  if (DEBUG) {
    if (rc == true) {
      Serial.print("Success sending MQTT message - ");
      printLocalTime();
      Serial.println();
    }
  }

  if (rc == false) {
    if (DEBUG) {
      Serial.println(error_message);
    }
    String error_message = "";
    restartEps32(error_message);
  }
    
  // Serial.print ficher JSON
  
  if (DEBUG) {
    char buffer[700];
    serializeJsonPretty(doc, buffer);
    Serial.println(buffer);
  }

  // Disconnect mqtt server

  void disconned();
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
